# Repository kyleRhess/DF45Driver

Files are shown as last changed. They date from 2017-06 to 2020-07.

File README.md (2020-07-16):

# DF45 Motor Driver

## A low-level Arduino sketch for controlling the [Nanotec DF45](https://us.nanotec.com/products/1544-df45-brushless-dc-motor/) BLDC (Brushless DC) motor

\
\
This code was written for the Arduino Uno or any ATMega328.
\
The [motor driver module itself](https://kylerhess.github.io/driver.html) uses an embedded `ATMEGA328-AUR` and is proprietary to the controller PCB design.
\
The DF45 Driver relies on brushless motors with Hall-Effect sensor feedback in order to function properly. These motors operate under `Four Quadrant Motor Control`.

Alternate text

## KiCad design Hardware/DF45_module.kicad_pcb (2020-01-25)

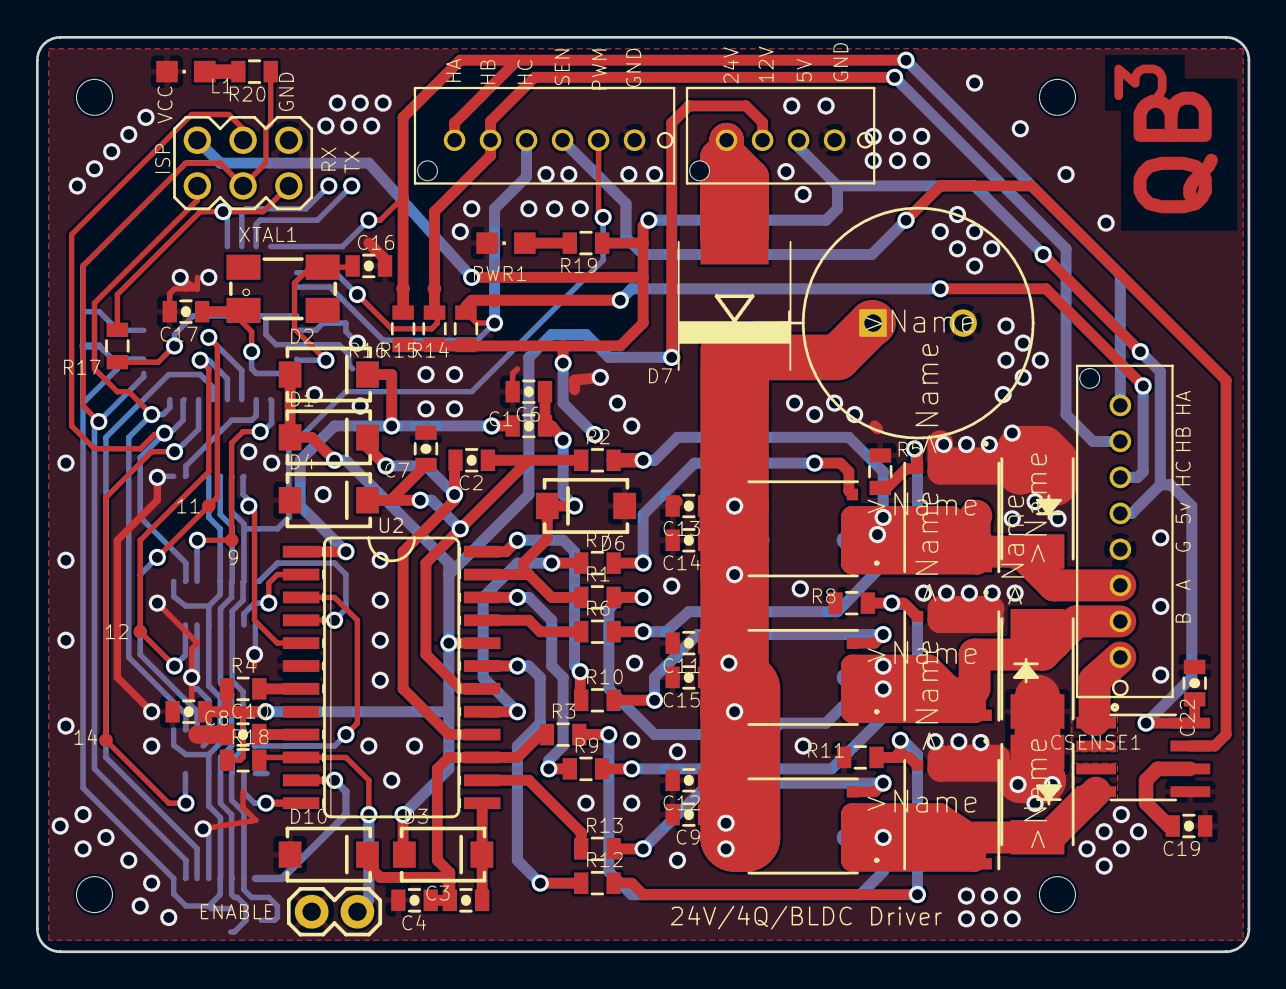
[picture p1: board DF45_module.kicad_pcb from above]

Board: 2 copper layers, 67.3 x 50.8 mm, 89 parts (0 on the bottom side), 56 nets.

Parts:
@HOLE0, @HOLE1, @HOLE2, @HOLE3: (no value)
C1, C2, C3: 0.22uF; 0805-CAP
C4, C6, C7, C19, C22: 1nF; 0805-CAP
C8, C11, C12, C13: 1uF; 0805-CAP
C9, C14, C15: 20nF; 0805-CAP
C10: 470pF; 0805-CAP
C16, C17: 22pF; 0805-CAP
C18, C20, C21: 0.1uF; 0805-CAP
C23: 1000uF; PCAP_125X25
CR1, CR2, CR3, CR4, CR5, CR6: SD2114S040S8R0; SD2114
CSENSE1: ACS712; SO08
D1, D2, D3, D4, D6, D10: DIODESMA; SMA-DIODE
D7: SCHOTTKY-DIODESMC; SMC
J1: M02PTH; 1X02
L1: LEDCHIPLED_0805; CHIPLED_0805
PWR1: LEDCHIPLED_0805; CHIPLED_0805
Q1, Q2, Q3, Q4, Q5, Q6: CSD18537NQ5A; DQJ8
R1, R2, R3, R6, R7, R9, R10, R12, R13: 4.7; 0805
R4: 15k; 0805
R5, R8, R11: 20k; 0805
R14, R15, R16, R17, R18, R20: 10k; 0805
R19: 300; 0805
SV1: MA03-2
TP1, TP2, TP3, TP4, TP5, TP6, TP7, TP8, TP9: TEST-POINT3; PAD.03X.03
U2: HIP408624-SOIC; 24-SOIC
U3, U4, U5: 74HC153TSSOP-16; TSSOP-16
U6: 741G04DCK; SC70-5
U7: ATMEGA328-AUR; 32A
U$1: PA-CON8TH; PA-CON
U$2: PA-CON6
U$4: PA-CON4
XTAL1: CRYSTALCTS406; CTS406

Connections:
/5V: C18.1, C20.1, C21.2, C22.1, CSENSE1.8, R14.1, R15.1, R16.1, R17.1, R19.1, SV1.2, U3.4, U3.12, U3.16, U4.4, U4.12, U4.16, U5.4, U5.12, U5.16, U6.5, U7.4, U7.6, U7.18, U7.20, U$1.6, U$4.2
/12V: C8.1, D1.A, D2.A, D3.A, R4.1, R18.1, U2.20, U$4.3
/24V: D7.A, U$4.4
/AE: SV1.4, U3.15, U7.15
/AHI: U2.5, U3.7
/AHO: R7.1, U2.17
/ALI: U2.4, U3.9
/ALO: R6.1, U2.21
/AS1: TP1.P$1, U3.14, U7.9
/AS2: TP5.P$1, U3.2, U7.10
/BE: SV1.1, U4.15, U7.16
/BHI: U2.2, U4.7
/BHO: R10.1, U2.24
/BLI: U2.3, U4.9
/BLO: R9.1, U2.22
/BS1: TP7.P$1, U4.14, U7.11
/BS2: TP6.P$1, U4.2, U7.12
/CE: R20.1, SV1.3, U5.15, U7.17
/CHI: U2.12, U5.7
/CHO: R13.1, U2.14
/CLI: U2.11, U5.9
/CLO: R12.1, U2.19
/CS1: TP9.P$1, U5.14, U7.13
/CS2: TP8.P$1, U5.2, U7.14
/DIS: J1.1, R18.2, U2.10
/FILT: C19.2, CSENSE1.6
/HAL_A: R16.2, TP2.P$1, U7.32, U$1.9, U$2.6
/HAL_B: R15.2, TP3.P$1, U7.1, U$1.8, U$2.5
/HAL_C: R14.2, TP4.P$1, U7.2, U$1.7, U$2.4
/MOS: C9.1, C11.1, C12.1, C13.1, C14.1, C15.1, C23.1, CR1.1, CR3.1, CR5.1, D7.C, Q1.5, Q1.6, Q1.7, Q1.8, Q3.5, Q3.6, Q3.7, Q3.8, Q5.5, Q5.6, Q5.7, Q5.8
/PHA: CR1.2, CR2.1, Q1.1, Q1.2, Q1.3, Q2.5, Q2.6, Q2.7, Q2.8, R2.2, U$1.4
/PHB: CR3.2, CR4.1, Q3.1, Q3.2, Q3.3, Q4.5, Q4.6, Q4.7, Q4.8, R1.2, U$1.3
/PHC: CR5.2, CR6.1, CSENSE1.1, CSENSE1.2, CSENSE1.3, CSENSE1.4, Q5.1, Q5.2, Q5.3, Q6.5, Q6.6, Q6.7, Q6.8, R3.2, U$1.2
/PWM: U3.6, U3.10, U4.6, U4.10, U5.6, U5.10, U6.2, U$2.2
/RST: R17.2, SV1.5, U7.29
/SENSE: CSENSE1.7, U$2.3
/~PWM~: U3.5, U3.11, U4.5, U4.11, U5.5, U5.11, U6.4
GND: C4.2, C6.2, C7.2, C8.2, C9.2, C10.1, C11.2, C12.2, C13.2, C14.2, C15.2, C16.2, C17.2, C18.2, C19.1, C20.2, C21.1, C22.2, C23.2, CR2.2, CR4.2, CR6.2, CSENSE1.5, D4.A, D6.A, D10.A, J1.2, L1.C, PWR1.C, Q2.1, Q2.2, Q2.3, Q4.1, Q4.2, Q4.3, Q6.1, Q6.2, Q6.3, R5.1, R8.1, R11.1, SV1.6, U2.6, U3.1, U3.3, U3.8, U3.13, U4.1, U4.3, U4.8, U4.13, U5.1, U5.3, U5.8, U5.13, U6.3, U7.3, U7.5, U7.21, U$1.5, U$2.1, U$4.1
unnamed: C1.1, D2.C, U2.1
unnamed: C1.2, C6.1, D6.C, R1.1, U2.23
unnamed: C2.1, C7.1, D4.C, R2.1, U2.18
unnamed: C2.2, D1.C, U2.16
unnamed: C3.1, C4.1, D10.C, R3.1, U2.15
unnamed: C3.2, D3.C, U2.13
unnamed: C10.2, U2.9
unnamed: C16.1, U7.7, XTAL1.3
unnamed: C17.1, U7.8, XTAL1.1
unnamed: L1.A, R20.2
unnamed: PWR1.A, R19.2
unnamed: Q1.4, R7.2
unnamed: Q2.4, R5.2, R6.2
unnamed: Q3.4, R10.2
unnamed: Q4.4, R8.2, R9.2
unnamed: Q5.4, R13.2
unnamed: Q6.4, R11.2, R12.2
unnamed: R4.2, U2.7

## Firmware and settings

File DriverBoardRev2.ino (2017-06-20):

//________  __________ .__                                                                   
//\_____  \ \______   \|  |__  _____     ______  ____                                        
//  _(__  <  |     ___/|  |  \ \__  \   /  ___/_/ __ \                                       
// /       \ |    |    |   Y  \ / __ \_ \___ \ \  ___/                                       
///______  / |____|    |___|  /(____  //____  > \___  >                                      
//       \/                 \/      \/      \/      \/                                       
//__________ .____     ________   _________    ________           .__                        
//\______   \|    |    \______ \  \_   ___ \   \______ \  _______ |__|___  __  ____  _______ 
// |    |  _/|    |     |    |  \ /    \  \/    |    |  \ \_  __ \|  |\  \/ /_/ __ \ \_  __ \
// |    |   \|    |___  |    `   \\     \____   |    `   \ |  | \/|  | \   / \  ___/  |  | \/
// |______  /|_______ \/_______  / \______  /  /_______  / |__|   |__|  \_/   \___  > |__|   
//        \/         \/        \/         \/           \/                         \/         

// Kyle Hess
// 05-29-2017
// University of Washington
// EE 449

//Controls the switching of a three-phase inverter bridge
//for driving a BLDC three-phase motor. This code is 
//proprietary, and meant to be used with the custom DF45
//motor driver board for QB^3.

//SPEED
float RPM = 0.0;
float stepCount = 0.0;
int prevTime = 0;

// MUX BIT OUTPUTS
const int muxA0 = 5; //PD5
const int muxA1 = 6; //PD6
const int muxAe = 11; //PB3
const int muxB0 = 7; //PD7

const int muxB1 = 8; //PB0
const int muxBe = 12; //PB4
const int muxC0 = 9; //PB1
const int muxC1 = 10; //PB2
const int muxCe = 13; //PB5

// HALL SENSOR INPUTS
const int HallA = 2; //PD2
const int HallB = 3; //PD3
const int HallC = 4; //PD4

// HALL EFFECT READING VARS
char my_varA = 0;
char my_varB = 0;
char my_varC = 0;
int A;
int B;
int C;

// MOTOR STEP LOCATION
long curStep = 0;
long prevStep = 0;
long prevStep2 = 0;

void setup() {
  //Initialize Hall effect input pins
  pinMode(HallA, INPUT);
  pinMode(HallB, INPUT);
  pinMode(HallC, INPUT);

  //Initialize outputs/inputs
  DDRD = 0b11100000;
  DDRB = 0b11111111;

  //Detect the initial rotor step location
  A = digitalRead(HallA);
  B = digitalRead(HallB);
  C = digitalRead(HallC);
  if (A == 1 && B == 0 && C == 0) {
    curStep = 1;
  } else if (A == 1 && B == 1 && C == 0) {
    curStep = 2;
  } else if (A == 0 && B == 1 && C == 0) {
    curStep = 3;
  } else if (A == 0 && B == 1 && C == 1) {
    curStep = 4;
  } else if (A == 0 && B == 0 && C == 1) {
    curStep = 5;
  } else {
    curStep = 6;
  }

  //Initialize all MOSFETs LOW!
  turnOff();
}

void loop() {
  runMotor();
}

void runMotor() {
  // READ & GET THE HALL SENSOR STATES
  A = (PIND & (1 << PD2));
  B = (PIND & (1 << PD3));
  C = (PIND & (1 << PD4));

  prevStep = curStep;
  if (A == 4 && B == 0 && C == 0) {
    PORTD = 0b00000000;
    PORTB = 0b00010011;
    curStep = 1;
  } else if (A == 4 && B == 8 && C == 0) {
    PORTD = 0b01000000;
    PORTB = 0b00001010;
    curStep = 2;
  } else if (A == 0 && B == 8 && C == 0) {
    PORTD = 0b00100000;
    PORTB = 0b00100100;
    curStep = 3;
  } else if (A == 0 && B == 8 && C == 16) {
    PORTD = 0b00100000;
    PORTB = 0b00010001;
    curStep = 4;
  } else if (A == 0 && B == 0 && C == 16) {
    PORTD = 0b11000000;
    PORTB = 0b00001000;
    curStep = 5;
  } else if (A == 4 && B == 0 && C == 16) {
    PORTD = 0b10000000;
    PORTB = 0b00100100;
    curStep = 6;
  }
}

void turnOff() {
  PORTD = 0b01001110;
  PORTB = 0b00111101;
}

void getRpm() {
  // CALCULATE RPM
  if (curStep != prevStep) {
    stepCount++;
  }
  prevStep = curStep;
  if (millis() - prevTime >= 250) {
    RPM = (stepCount / 48.0) * 240.0;
    stepCount = 0.0;
    prevTime = millis();
  }
}

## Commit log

2020-01-25 Added hardware files.
    [DF45_module.kicad_pcb, DF45_module.sch]
2020-01-27 Updated hardware to use latest library references.
    [DF45_module.sch]
